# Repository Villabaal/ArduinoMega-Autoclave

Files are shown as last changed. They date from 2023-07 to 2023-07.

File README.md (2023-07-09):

# Arduino Mega Autoclave
## Platformio project with avr-gcc 11.2
Autoclave digital controler programmed on platformIO with the arduino framework using c++20 connected via R232 to its interface.

## Kicad project
Folder with kicad files, Schematic, PCB, components list.
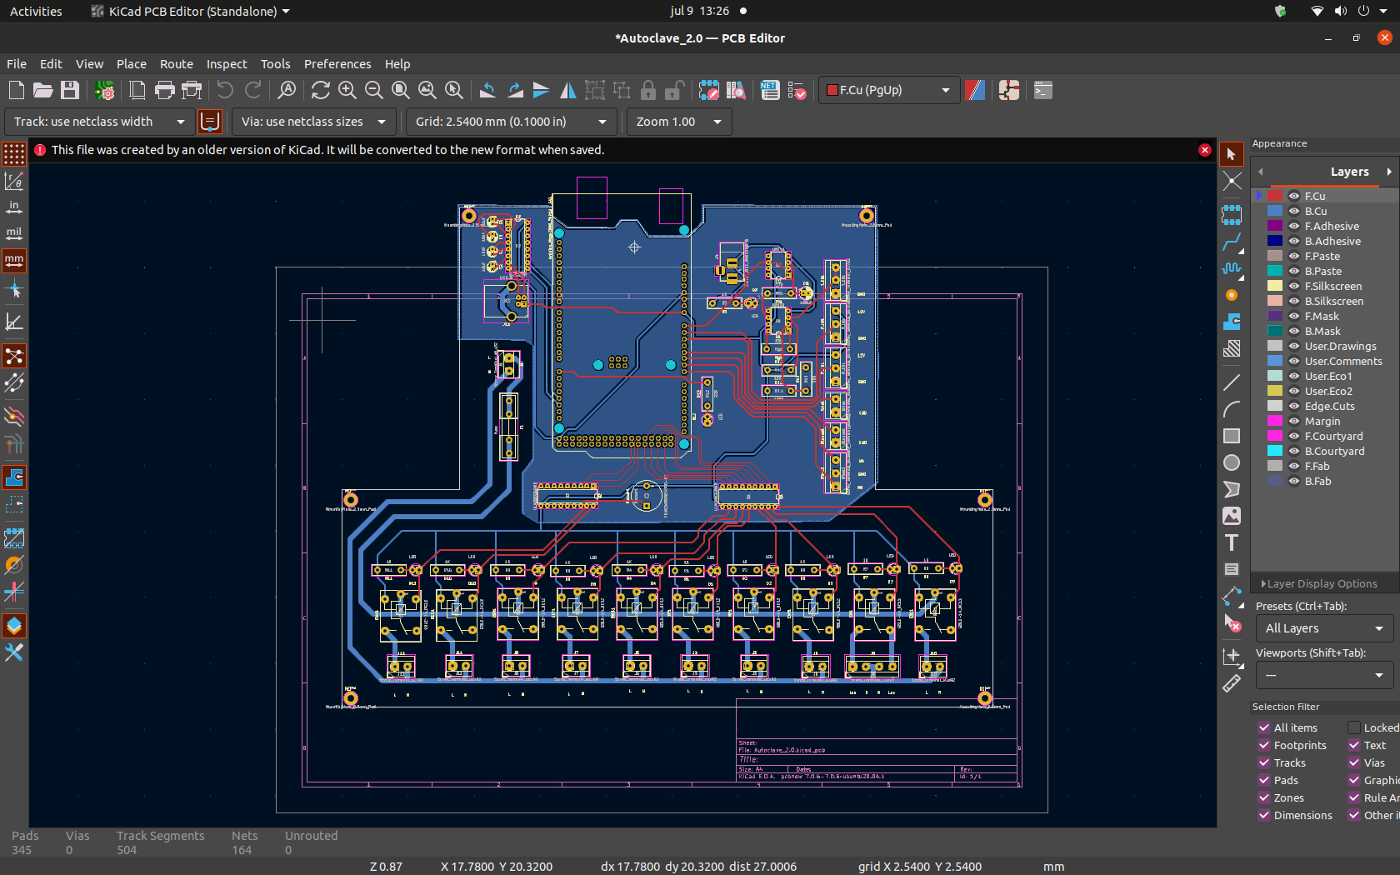
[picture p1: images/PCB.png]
PBC screenshot

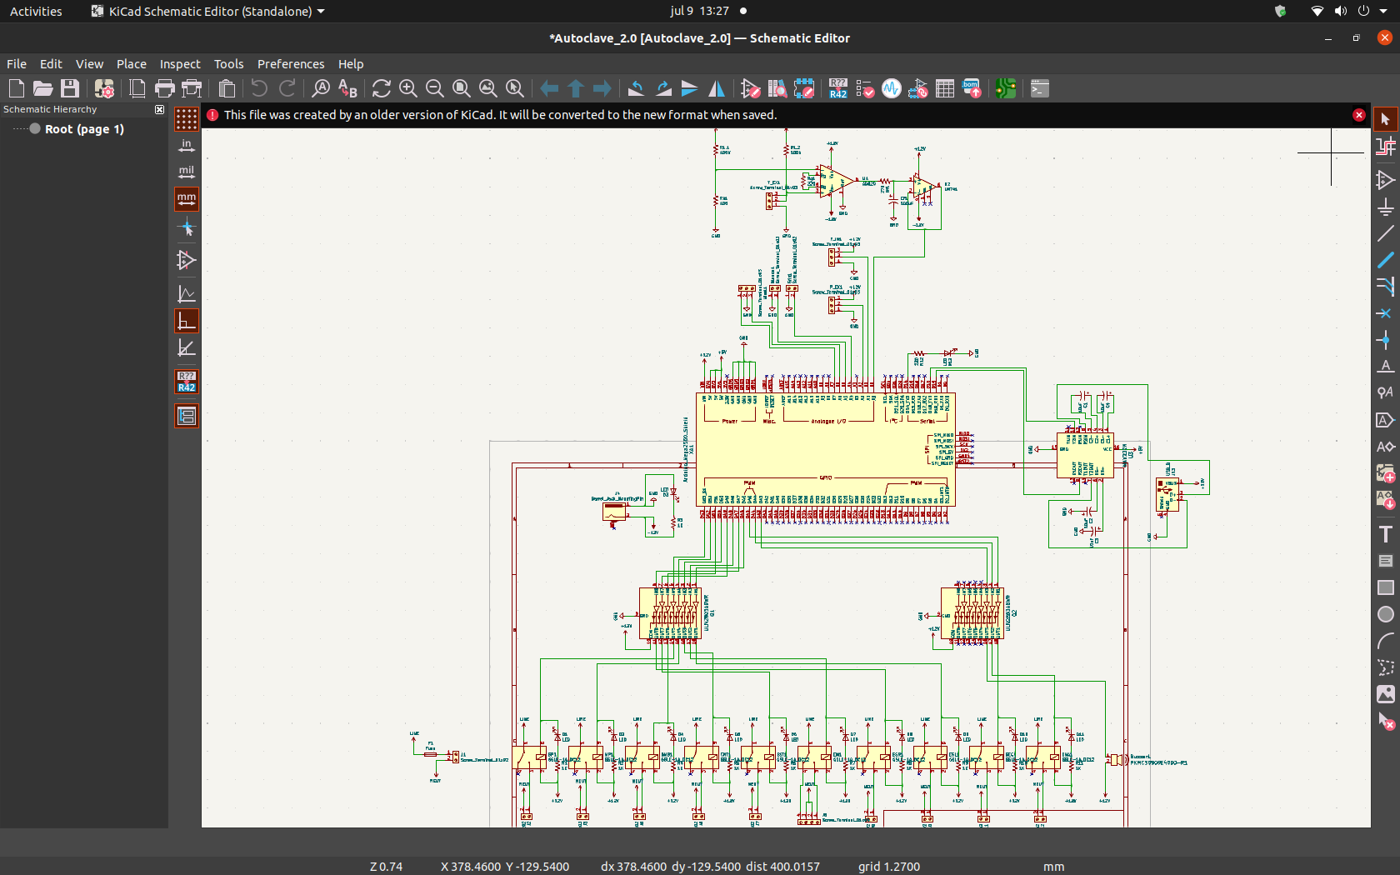
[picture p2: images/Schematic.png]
Schematic screenshot


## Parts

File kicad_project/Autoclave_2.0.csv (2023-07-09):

Reference | Quantity | Value | Footprint | DK_Detail_Page | Description | Digi-Key_PN | Family | MPN | Manufacturer | Status
Buzzer1 | 1 | PKMCS0909E4000-R1 | Buzzer_Beeper:Buzzer_12x9.5RM7.6 | /product-detail/en/murata-electronics-north-america/PKMCS0909E4000-R1/490-9647-1-ND/4878401 | AUDIO PIEZO TRANSDUCER 12.5V SMD | 490-9647-1-ND | Alarms, Buzzers, and Sirens | PKMCS0909E4000-R1 | Murata Electronics North America | Active
C1 C2 C3 C4 | 4 | 10uF | Capacitor_THT:CP_Radial_D4.0mm_P2.00mm
Cf1 | 1 | 100uF | Capacitor_THT:CP_Radial_D5.0mm_P2.00mm
D1 D2 D3 D4 D5 D6 D7 D8 D9 D10 D11 D12 | 12 | LED | digikey-footprints:LED_3mm_Radial
F1 | 1 | Fuse | Fuse_Holders_and_Fuses:Fuseholder5x20_horiz_open_inline_Type-I
J1 Gris1 Blanca1 J2 J3 J5 J6 J7 J9 J10 J11 J12 | 12 | Screw_Terminal_01x02 | TerminalBlock:TerminalBlock_Altech_AK300-2_P5.00mm
J13 | 1 | USB_B | Connector_USB:USB_B_OST_USB-B1HSxx_Horizontal
J4 | 1 | Barrel_Jack_MountingPin | digikey-footprints:Barrel_Jack_5.5mmODx2.1mmID_PJ-102A
J8 | 1 | Screw_Terminal_01x04 | TerminalBlock:TerminalBlock_Altech_AK300-4_P5.00mm
MP1 BMB1 CNT1 EST1 EM1 ESR1 ESL1 SEC1 ENA1 SP1 | 10 | G5LE-14_DC12 | Relay_THT:Relay_SPDT_SANYOU_SRD_Series_Form_C | /product-detail/en/omron-electronics-inc-emc-div/G5LE-14-DC12/Z1012-ND/280369 | RELAY GEN PURPOSE SPDT 10A 12V | Z1012-ND | Power Relays, Over 2 Amps | G5LE-14 DC12 | Omron Electronics Inc-EMC Div | Active
Q1 Q2 | 2 | ULN2803ADWR | Package_DIP:DIP-18_W7.62mm | /product-detail/en/texas-instruments/ULN2803ADWR/296-15777-1-ND/598088 | TRANS 8NPN DARL 50V 0.5A 18SO | 296-15777-1-ND | Transistors - Bipolar (BJT) - Arrays | ULN2803ADWR | Texas Instruments | Active
R1 R2 R3 R4 R5 R6 R7 R8 R9 R10 R11 | 11 | 1K | Resistor_THT:R_Box_L13.0mm_W4.0mm_P9.00mm
R1.1 R1.2 | 2 | 100K | Resistor_THT:R_Box_L13.0mm_W4.0mm_P9.00mm
Rb1 | 1 | 100 | Resistor_THT:R_Box_L13.0mm_W4.0mm_P9.00mm
Rf1 | 1 | 270 | Resistor_THT:R_Box_L13.0mm_W4.0mm_P9.00mm
Rg1 R12 | 2 | 220 | Resistor_THT:R_Box_L13.0mm_W4.0mm_P9.00mm
T_EX1 P_IN1 P_EX1 Nivel1 | 4 | Screw_Terminal_01x03 | TerminalBlock:TerminalBlock_Altech_AK300-3_P5.00mm
U1 | 1 | AD620 | Package_DIP:DIP-8_W7.62mm
U2 | 1 | LM741 | Package_DIP:DIP-8_W7.62mm
U3 | 1 | MAX232N | Package_DIP:DIP-16_W7.62mm | /product-detail/en/texas-instruments/MAX232N/296-1402-5-ND/277048 | IC DUAL EIA-232 DRVR/RCVR 16-DIP | 296-1402-5-ND | Interface - Drivers, Receivers, Transceivers | MAX232N | Texas Instruments | Active

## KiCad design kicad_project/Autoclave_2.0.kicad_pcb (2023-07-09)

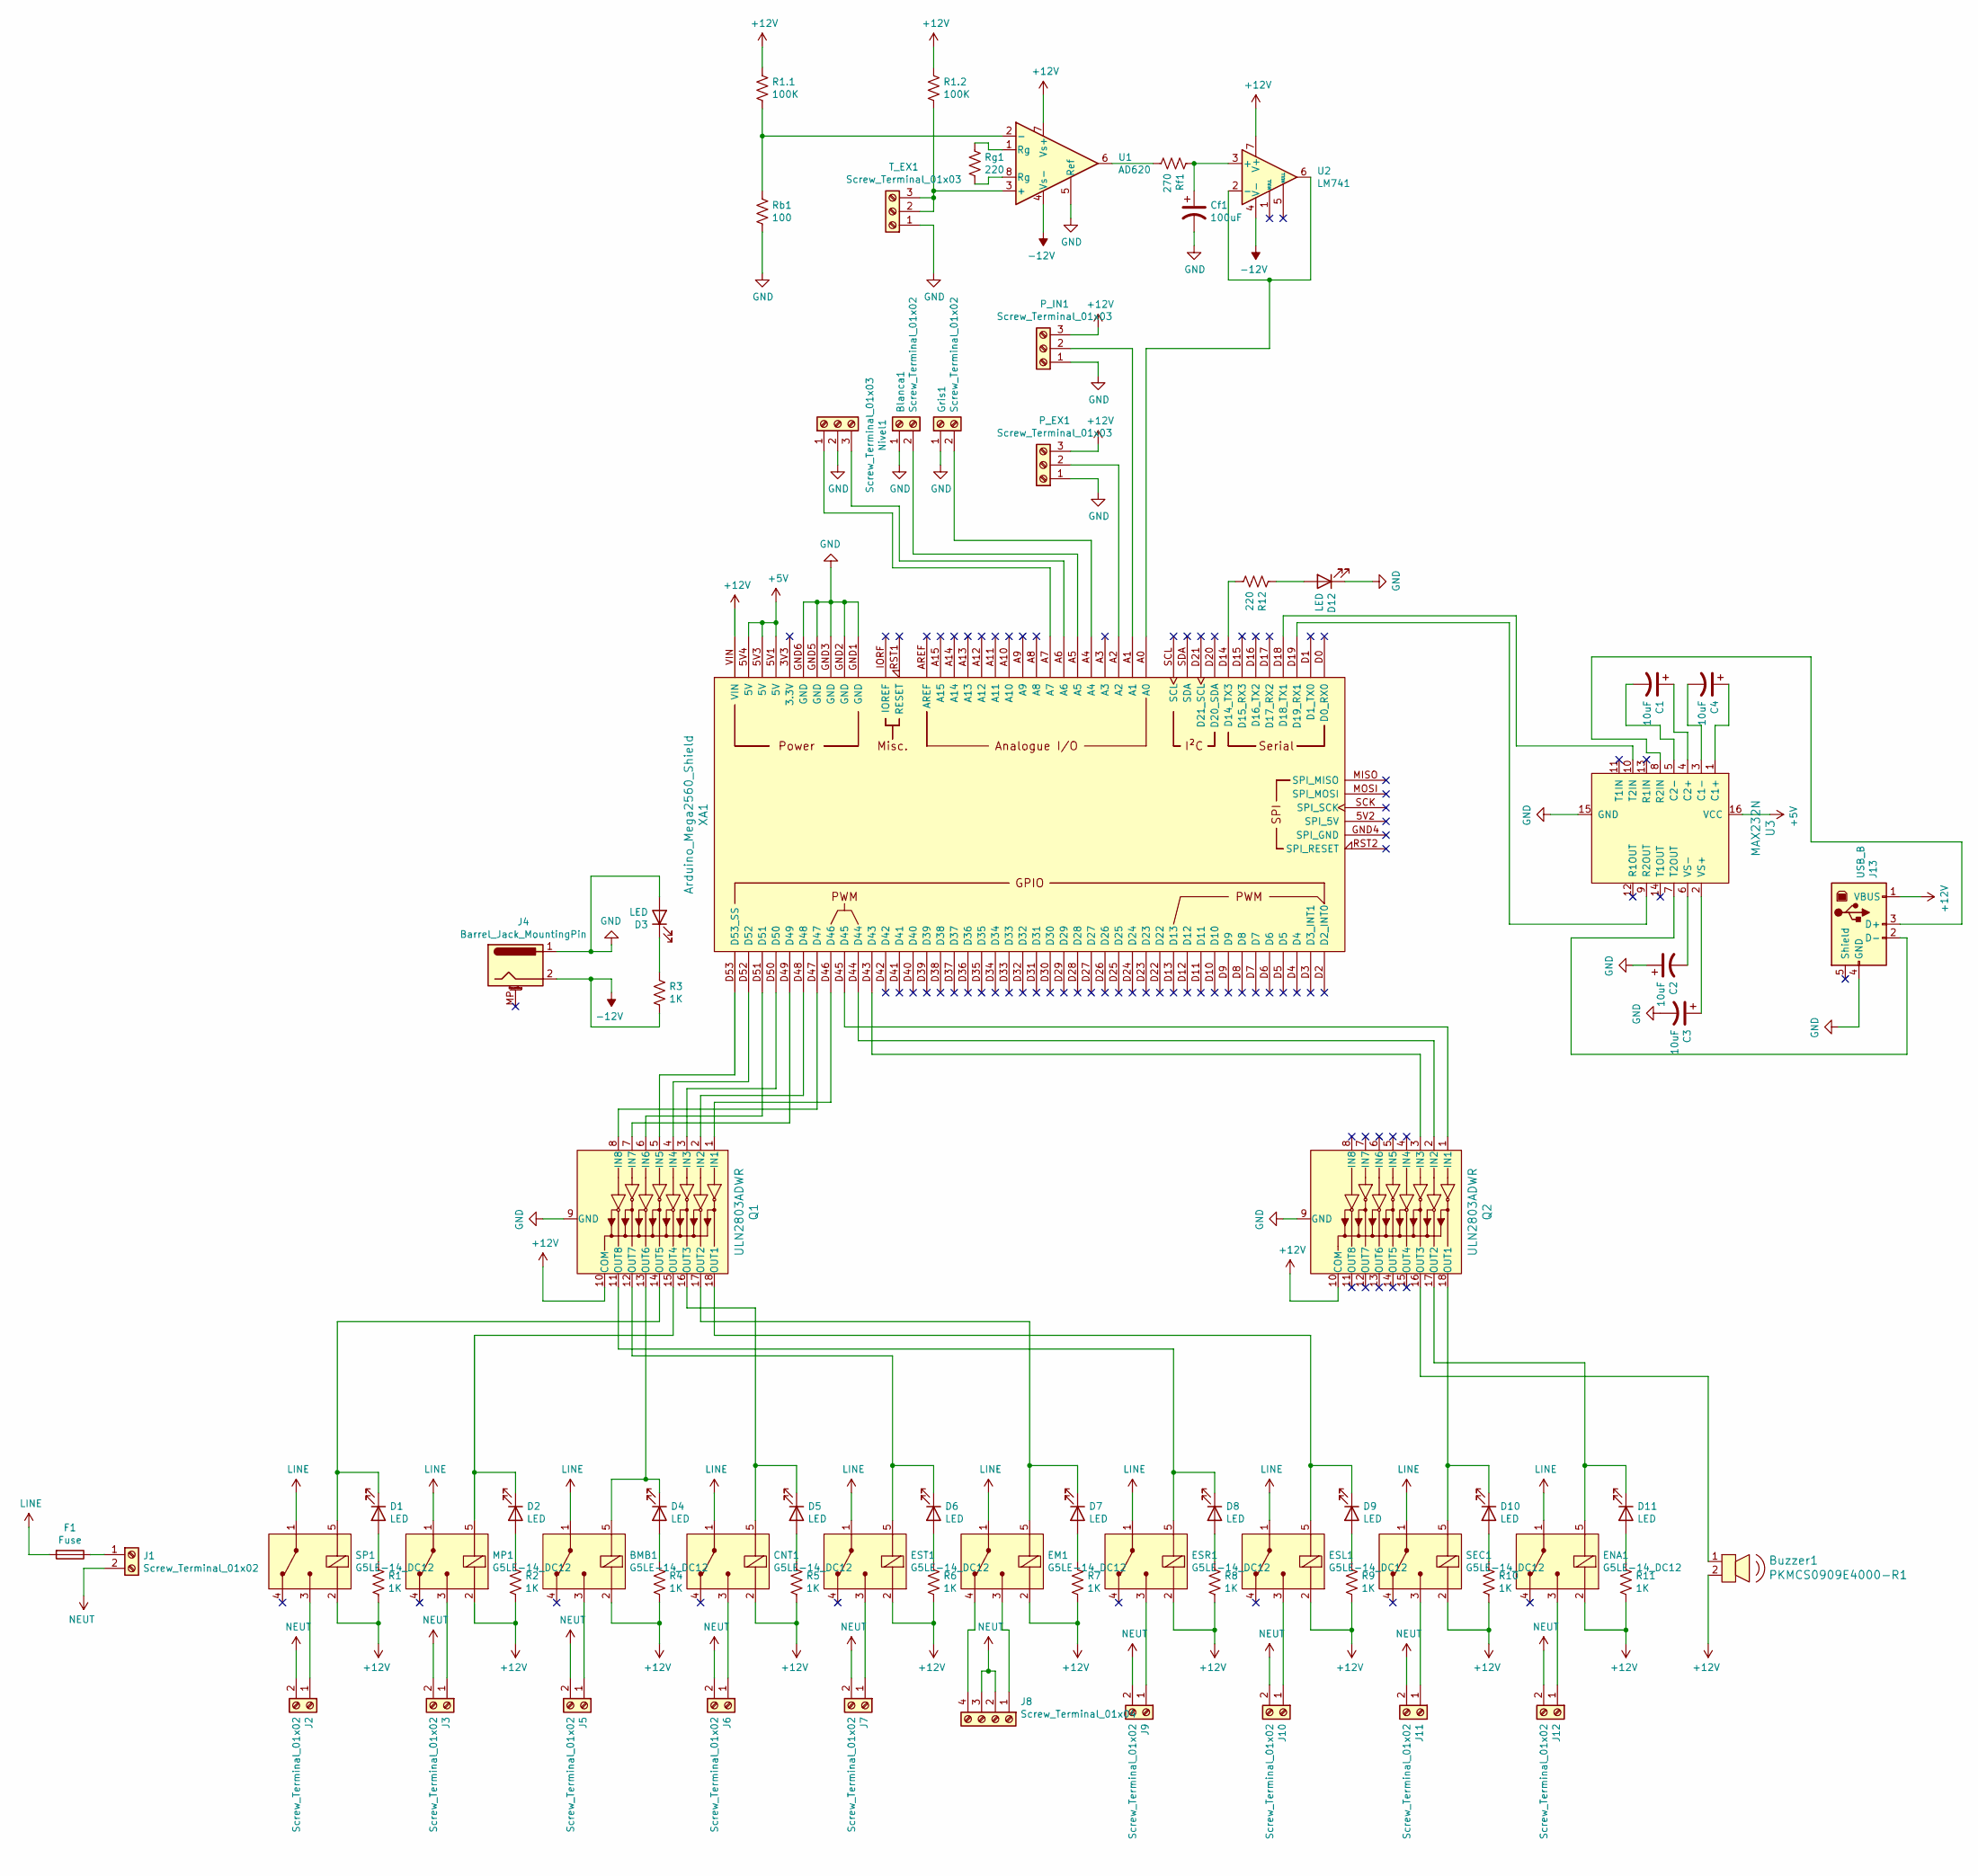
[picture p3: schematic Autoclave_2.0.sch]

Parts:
BMB1: G5LE-14_DC12; Relay_SPDT_SANYOU_SRD_Series_Form_C; MPN G5LE-14 DC12; Digi-Key_PN Z1012-ND
Blanca1: Screw_Terminal_01x02; TerminalBlock_MetzConnect_Type055_RT01502HDWU_1x02_P5.00mm_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
Buzzer1: PKMCS0909E4000-R1; Buzzer_12x9.5RM7.6; MPN PKMCS0909E4000-R1; Digi-Key_PN 490-9647-1-ND
C1, C2, C3, C4: 10uF; CP_Radial_D4.0mm_P2.00mm
CNT1: G5LE-14_DC12; Relay_SPDT_SANYOU_SRD_Series_Form_C; MPN G5LE-14 DC12; Digi-Key_PN Z1012-ND
Cf1: 100uF; CP_Radial_D5.0mm_P2.00mm
D1, D2, D3, D4, D5, D6, D7, D8, D9, D10, D11, D12: LED; LED_3mm_Radial
EM1: G5LE-14_DC12; Relay_SPDT_SANYOU_SRD_Series_Form_C; MPN G5LE-14 DC12; Digi-Key_PN Z1012-ND
ENA1: G5LE-14_DC12; Relay_SPDT_SANYOU_SRD_Series_Form_C; MPN G5LE-14 DC12; Digi-Key_PN Z1012-ND
ESL1: G5LE-14_DC12; Relay_SPDT_SANYOU_SRD_Series_Form_C; MPN G5LE-14 DC12; Digi-Key_PN Z1012-ND
ESR1: G5LE-14_DC12; Relay_SPDT_SANYOU_SRD_Series_Form_C; MPN G5LE-14 DC12; Digi-Key_PN Z1012-ND
EST1: G5LE-14_DC12; Relay_SPDT_SANYOU_SRD_Series_Form_C; MPN G5LE-14 DC12; Digi-Key_PN Z1012-ND
F1: Fuse; Fuseholder5x20_horiz_open_inline_Type-I
Gris1: Screw_Terminal_01x02; TerminalBlock_MetzConnect_Type055_RT01502HDWU_1x02_P5.00mm_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
J1, J2, J3, J5, J6, J7, J9, J10, J11, J12: Screw_Terminal_01x02; TerminalBlock_MetzConnect_Type055_RT01502HDWU_1x02_P5.00mm_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
J4: Barrel_Jack_MountingPin; BarrelJack_Horizontal
J8: Screw_Terminal_01x04; TerminalBlock_MetzConnect_Type101_RT01604HBWC_1x04_P5.08mm_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
J13: USB_B; USB_B_OST_USB-B1HSxx_Horizontal
MP1: G5LE-14_DC12; Relay_SPDT_SANYOU_SRD_Series_Form_C; MPN G5LE-14 DC12; Digi-Key_PN Z1012-ND
Nivel1: Screw_Terminal_01x03; TerminalBlock_MetzConnect_Type101_RT01603HBWC_1x03_P5.08mm_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
P_EX1: Screw_Terminal_01x03; TerminalBlock_MetzConnect_Type101_RT01603HBWC_1x03_P5.08mm_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
P_IN1: Screw_Terminal_01x03; TerminalBlock_MetzConnect_Type101_RT01603HBWC_1x03_P5.08mm_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
Q1, Q2: ULN2803ADWR; DIP-18_W7.62mm; MPN ULN2803ADWR; Digi-Key_PN 296-15777-1-ND
R1, R2, R3, R4, R5, R6, R7, R8, R9, R10, R11: 1K; R_Box_L13.0mm_W4.0mm_P9.00mm
R1.1, R1.2: 100K; R_Box_L13.0mm_W4.0mm_P9.00mm
R12: 220; R_Box_L13.0mm_W4.0mm_P9.00mm
Rb1: 100; R_Box_L13.0mm_W4.0mm_P9.00mm
Rf1: 270; R_Box_L13.0mm_W4.0mm_P9.00mm
Rg1: 220; R_Box_L13.0mm_W4.0mm_P9.00mm
SEC1: G5LE-14_DC12; Relay_SPDT_SANYOU_SRD_Series_Form_C; MPN G5LE-14 DC12; Digi-Key_PN Z1012-ND
SP1: G5LE-14_DC12; Relay_SPDT_SANYOU_SRD_Series_Form_C; MPN G5LE-14 DC12; Digi-Key_PN Z1012-ND
T_EX1: Screw_Terminal_01x03; TerminalBlock_MetzConnect_Type101_RT01603HBWC_1x03_P5.08mm_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
U1: AD620; DIP-8_W7.62mm
U2: LM741; DIP-8_W7.62mm
U3: MAX232N; DIP-16_W7.62mm; MPN MAX232N; Digi-Key_PN 296-1402-5-ND
XA1: Arduino_Mega2560_Shield

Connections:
+5V: U3.16 (VCC), XA1.5V1 (5V), XA1.5V3 (5V), XA1.5V4 (5V)
+12V: BMB1.2 (COIL), Buzzer1.2, CNT1.2 (COIL), EM1.2 (COIL), ENA1.2 (COIL), ESL1.2 (COIL), ESR1.2 (COIL), EST1.2 (COIL), J13.1 (VBUS), MP1.2 (COIL), P_EX1.3, P_IN1.3, Q1.10 (COM), Q2.10 (COM), R1.2, R1.1.1, R1.2.1, R2.2, R4.2, R5.2, R6.2, R7.2, R8.2, R9.2, R10.2, R11.2, SEC1.2 (COIL), SP1.2 (COIL), U1.7 (Vs+), U2.7 (V+), XA1.VIN
-12V: J4.2, R3.2, U1.4 (Vs-), U2.4 (V-)
GND: Blanca1.1, C2.1, C3.2, Cf1.2, D3.2 (A), D12.1 (K), Gris1.1, J4.1, J13.4 (GND), Nivel1.2, P_EX1.1, P_IN1.1, Q1.9 (GND), Q2.9 (GND), Rb1.2, T_EX1.1, U1.5 (Ref), U3.15 (GND), XA1.GND1 (GND), XA1.GND2 (GND), XA1.GND3 (GND), XA1.GND5 (GND), XA1.GND6 (GND)
LINE: BMB1.1 (COM), CNT1.1 (COM), EM1.1 (COM), ENA1.1 (COM), ESL1.1 (COM), ESR1.1 (COM), EST1.1 (COM), F1.2, MP1.1 (COM), SEC1.1 (COM), SP1.1 (COM)
NEUT: J1.2, J2.2, J3.2, J5.2, J6.2, J7.2, J8.2, J8.3, J9.2, J10.2, J11.2, J12.2
unnamed: BMB1.3 (NO), J5.1
unnamed: BMB1.5 (COIL), D4.1 (K), Q1.13 (OUT6)
unnamed: Blanca1.2, XA1.A5
unnamed: Buzzer1.1, Q2.16 (OUT3)
unnamed: C1.1, U3.4 (C2+)
unnamed: C1.2, U3.5 (C2-)
unnamed: C2.2, U3.6 (VS-)
unnamed: C3.1, U3.2 (VS+)
unnamed: C4.1, U3.1 (C1+)
unnamed: C4.2, U3.3 (C1-)
unnamed: CNT1.3 (NO), J6.1
unnamed: CNT1.5 (COIL), D5.1 (K), Q1.16 (OUT3)
unnamed: Cf1.1, Rf1.1, U2.3 (+)
unnamed: D1.1 (K), Q1.14 (OUT5), SP1.5 (COIL)
unnamed: D1.2 (A), R1.1
unnamed: D2.1 (K), MP1.5 (COIL), Q1.15 (OUT4)
unnamed: D2.2 (A), R2.1
unnamed: D3.1 (K), R3.1
unnamed: D4.2 (A), R4.1
unnamed: D5.2 (A), R5.1
unnamed: D6.1 (K), EST1.5 (COIL), Q1.12 (OUT7)
unnamed: D6.2 (A), R6.1
unnamed: D7.1 (K), EM1.5 (COIL), Q1.17 (OUT2)
unnamed: D7.2 (A), R7.1
unnamed: D8.1 (K), ESR1.5 (COIL), Q1.11 (OUT8)
unnamed: D8.2 (A), R8.1
unnamed: D9.1 (K), ESL1.5 (COIL), Q1.18 (OUT1)
unnamed: D9.2 (A), R9.1
unnamed: D10.1 (K), Q2.18 (OUT1), SEC1.5 (COIL)
unnamed: D10.2 (A), R10.1
unnamed: D11.1 (K), ENA1.5 (COIL), Q2.17 (OUT2)
unnamed: D11.2 (A), R11.1
unnamed: D12.2 (A), R12.1
unnamed: EM1.3 (NO), J8.1
unnamed: EM1.4 (NC), J8.4
unnamed: ENA1.3 (NO), J12.1
unnamed: ESL1.3 (NO), J10.1
unnamed: ESR1.3 (NO), J9.1
unnamed: EST1.3 (NO), J7.1
unnamed: F1.1, J1.1
unnamed: Gris1.2, XA1.A4
unnamed: J2.1, SP1.3 (NO)
unnamed: J3.1, MP1.3 (NO)
unnamed: J11.1, SEC1.3 (NO)
unnamed: J13.2 (D-), U3.7 (T2OUT)
unnamed: J13.3 (D+), U3.8 (R2IN)
unnamed: Nivel1.1, XA1.A7
unnamed: Nivel1.3, XA1.A6
unnamed: P_EX1.2, XA1.A2
unnamed: P_IN1.2, XA1.A1
unnamed: Q1.1 (IN1), XA1.D46
unnamed: Q1.2 (IN2), XA1.D48
unnamed: Q1.3 (IN3), XA1.D50
unnamed: Q1.4 (IN4), XA1.D52
unnamed: Q1.5 (IN5), XA1.D53 (D53_SS)
unnamed: Q1.6 (IN6), XA1.D51
unnamed: Q1.7 (IN7), XA1.D49
unnamed: Q1.8 (IN8), XA1.D47
unnamed: Q2.1 (IN1), XA1.D45
unnamed: Q2.2 (IN2), XA1.D44
unnamed: Q2.3 (IN3), XA1.D43
unnamed: R1.1.2, Rb1.1, U1.2 (-)
unnamed: R1.2.2, T_EX1.2, T_EX1.3, U1.3 (+)
unnamed: R12.2, XA1.D14 (D14_TX3)
unnamed: Rf1.2, U1.6
unnamed: Rg1.1, U1.1 (Rg)
unnamed: Rg1.2, U1.8 (Rg)
unnamed: U2.2 (-), U2.6, XA1.A0
unnamed: U3.9 (R2OUT), XA1.D19 (D19_RX1)
unnamed: U3.10 (T2IN), XA1.D18 (D18_TX1)

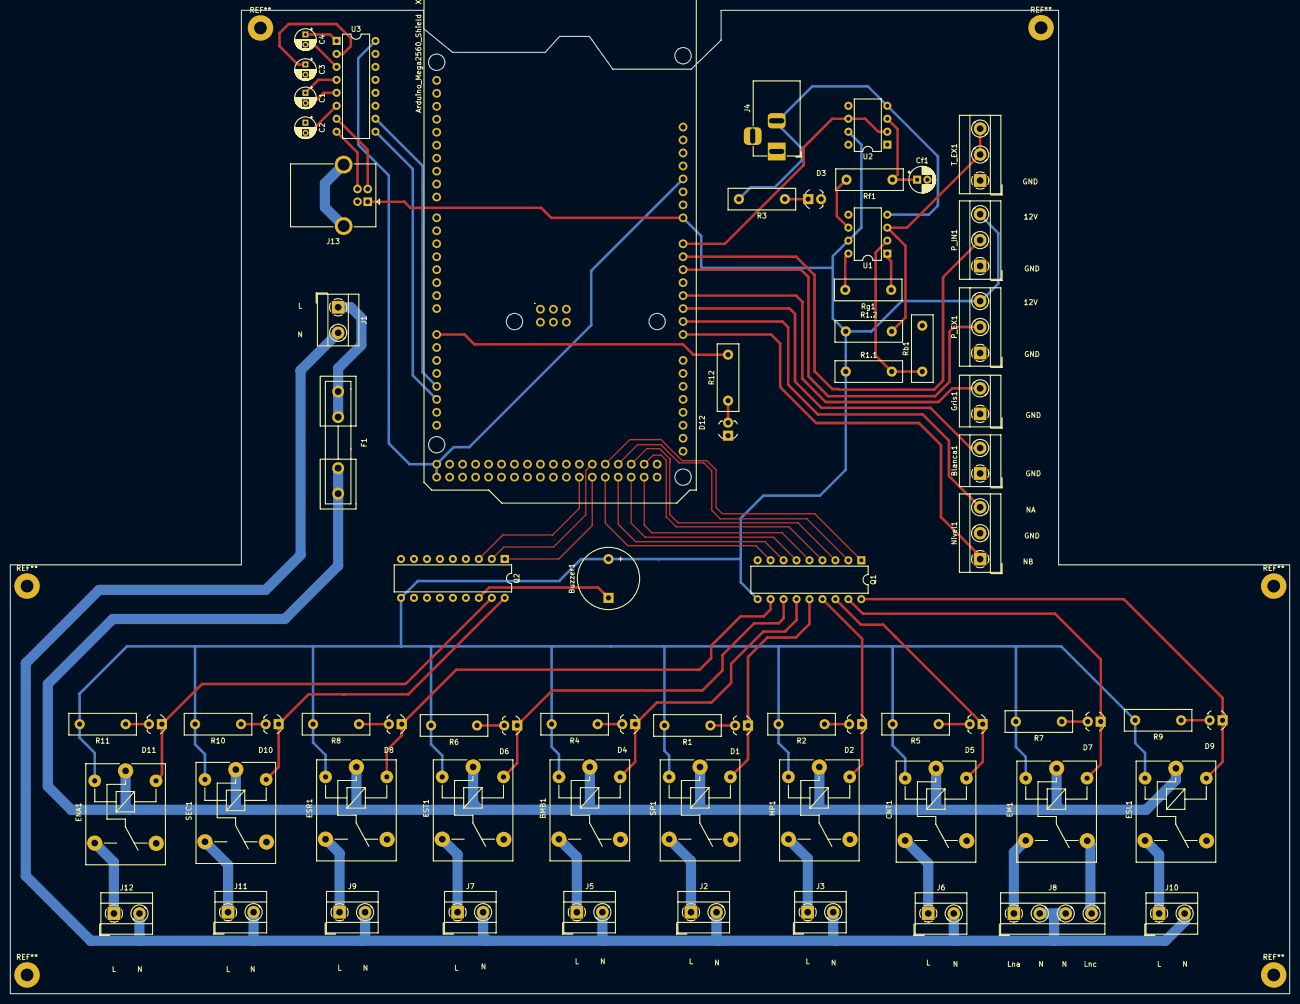
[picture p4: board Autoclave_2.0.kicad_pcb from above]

Board: 2 copper layers, 250.6 x 192.6 mm, 71 parts (1 on the bottom side), 76 nets.

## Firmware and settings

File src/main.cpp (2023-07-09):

#include "Communications.h"


//puerta con controlador Digital
using door = Doors::Engine<>;
//generdor con nivel encoder (mas chico de lo debido)
using GeneratorController = Generators::Controller< Generators::LevelSensUnFit >;
using generator = Generators::Engine< GeneratorController >;
//proceso, puerta y/o generador o nada
using process = Processes::Engine< generator,door >;
//Puerto general, para la comunicacion con la interfase
using Port = Comm::Port< process >;

void setup() { 
  //2 minutos de perro guardian del generadoy y 20 segundos de sobrellenado
  Port::setup( 120,20 );
}

// checar el puerto serie por requests y checar por errorres
void loop() {
  Port::loop();
}

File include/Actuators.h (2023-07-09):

#include "Metaprogrammig.h"
#include <Arduino.h>
class Relay{
    uint8_t const &relayPin;
public:
    constexpr Relay( uint8_t const &pin ): relayPin( pin )
        { pinMode( relayPin ,OUTPUT ) ; digitalWrite( relayPin, false ); }
    explicit operator bool() const { return digitalRead( relayPin ); }
    void operator() ( bool const &on ){ digitalWrite( relayPin,on ); }
    void operator() (){ digitalWrite( relayPin, !(*this) ); }
};        
//los relays estan fisicamente uno detras de otro (ENA=44,SEC=45...)
//asi que fasilita la funcion de operador [] ( this[ENA].doSomething() )
template<uint8_t N> class RelayVector{
    //clase privada
    Relay (*const Storage)[N];  uint8_t const &begin;
public:
    //construimos todos los relay en expresion constante!!
    constexpr RelayVector( auto const (&valvs)[N] ): 
        Storage( CE::arrayGenerator<Relay>( valvs ) ), begin( valvs[0] ){  }
    Relay& operator[] (const uint8_t &pos) { return (*Storage)[ pos - begin ] ; }
    void clear_all(){ for ( auto &&relay : (*Storage) ) relay(false);  }
};   

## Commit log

2023-07-09 template library
    [Autoclave_2.0-B_Cu.gbr, Autoclave_2.0-B_Mask.gbr, Autoclave_2.0-B_Paste.gbr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]
2024-03-25 Timers is a Repo
